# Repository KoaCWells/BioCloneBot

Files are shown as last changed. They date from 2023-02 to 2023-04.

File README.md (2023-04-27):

# BioCloneBot
The BioCloneBot is an open-source automated liquid handler developed to satisfy the requirements of my Master's thesis at Concordia University. Every aspect of the project including the parts, software, and 3D models have been made freely available GPL v3.0 license.

Visual Studio 2022 is required to make modifications to the front-end and the Arduino IDE or VS Code is required to modify the device firmware. Solidworks 2022 is required to open the original 3D model files. STLs have also been provided for printing.

#### Available Under GPL v3.0 License
 Copyright (C) 2023 Ke'Koa Wells

 BioCloneBot is free software: you can redistribute it and/or modify
 it under the terms of the GNU General Public License as published by
 the Free Software Foundation, either version 3 of the License, or
 (at your option) any later version.

 This program is distributed in the hope that it will be useful,
 but WITHOUT ANY WARRANTY; without even the implied warranty of
 MERCHANTABILITY or FITNESS FOR A PARTICULAR PURPOSE.  See the
 GNU General Public License for more details.

 You should have received a copy of the GNU General Public License
 along with this program.  If not, see <http://www.gnu.org/licenses/>.

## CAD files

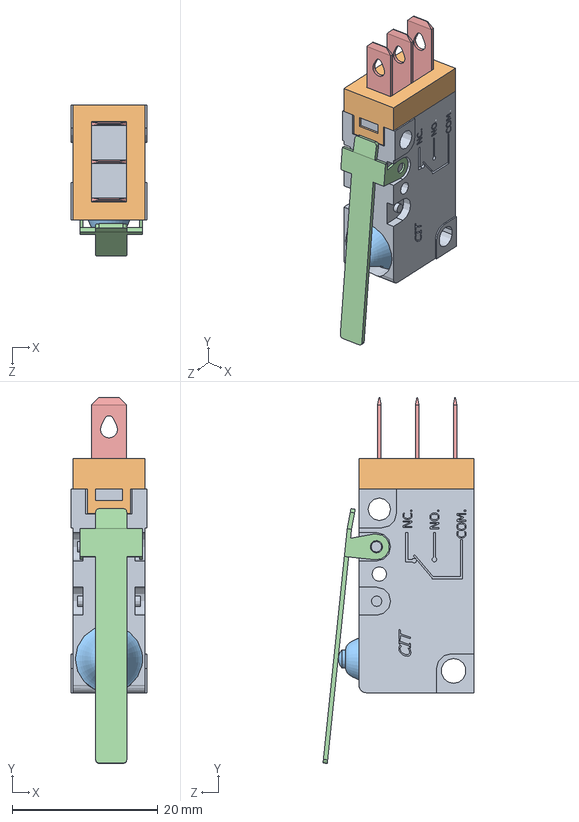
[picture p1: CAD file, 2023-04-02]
CADs/Syringe Pump/[CIT Relay & Switch]LimitSwitch.SLDASM
10.4 x 50.3 x 20.7 mm
VM3_Solid Body.stp
VM3_End Cap2.stp
Rubber Boot Push Button.stp
L88.stp
VM3S_TERMINAL_TEARDROP.stp x 3

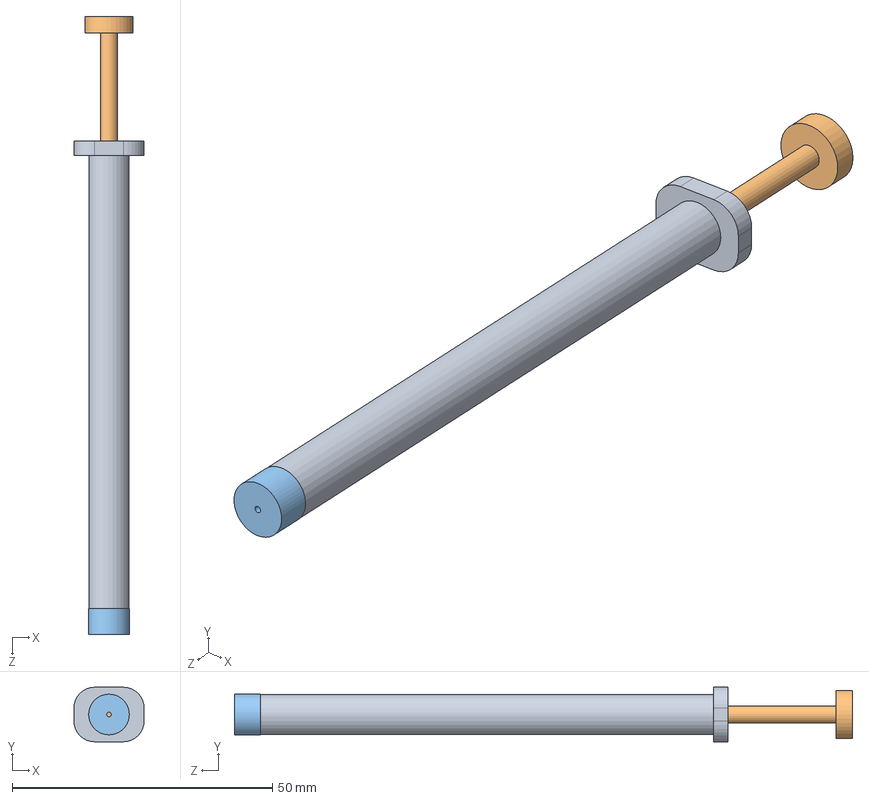
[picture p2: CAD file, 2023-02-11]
CADs/Syringe Pump/Syringe/Syringe.SLDASM
13.5 x 10.5 x 118.7 mm
SyringeBase
Plunger
RNNut

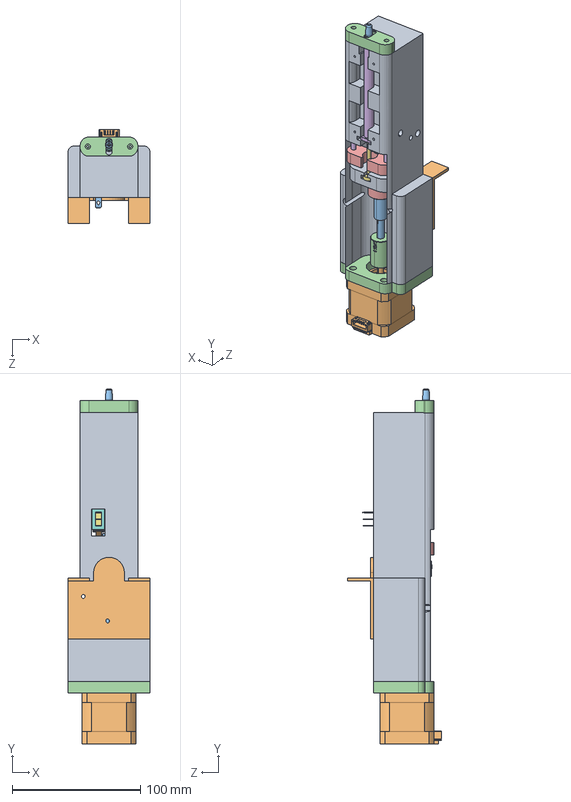
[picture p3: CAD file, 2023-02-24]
CADs/Syringe Pump/SyringePumpAssembly.SLDASM
64.0 x 276.3 x 73.5 mm
SyringePumpBaseV3
[MoonsSteppers] Stepper Motor.step
[Misumi]MTSRA10_100_S30_Q6
[Misumi]MRGS_16_5_6
[Misumi]MTSNR10
SyringeBase
Plunger
RNNut
PlungerHolder
200uLTipAdapter
TipEjectorBottomEnd
TipEjectorTopEnd
TipEjectorShaft x 2
VM3_Solid Body.stp
VM3_End Cap2.stp
Rubber Boot Push Button.stp
L88.stp
VM3S_TERMINAL_TEARDROP.stp x 3
MotorHolder

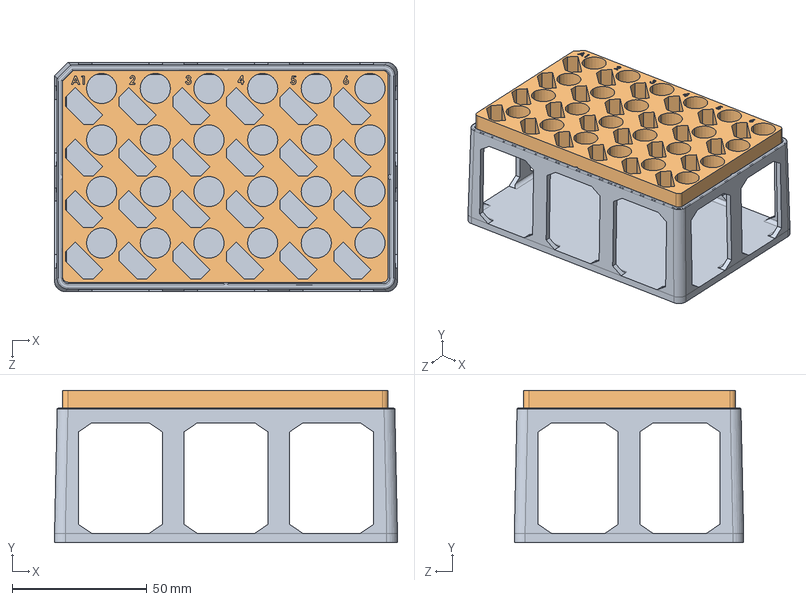
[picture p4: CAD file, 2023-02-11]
CADs/Labware/Tubestand.SLDASM
127.5 x 56.6 x 85.2 mm
OpenTrons_Base_Stand_50mm.step
OpenTrons_1.5mL_rack.step

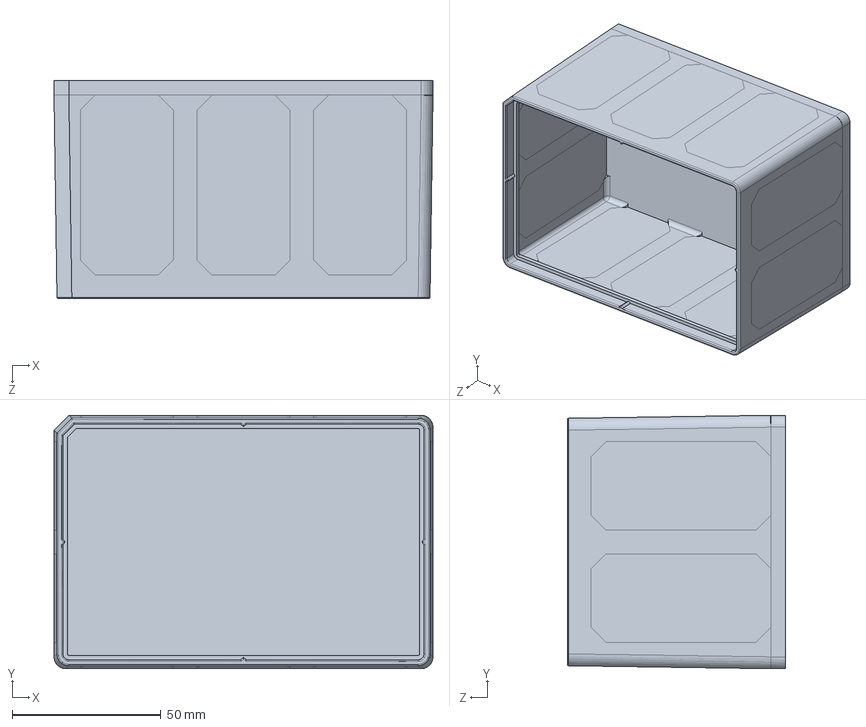
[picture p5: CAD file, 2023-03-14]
CADs/Labware/SolidTubeStand.SLDPRT
127.5 x 85.2 x 73.5 mm

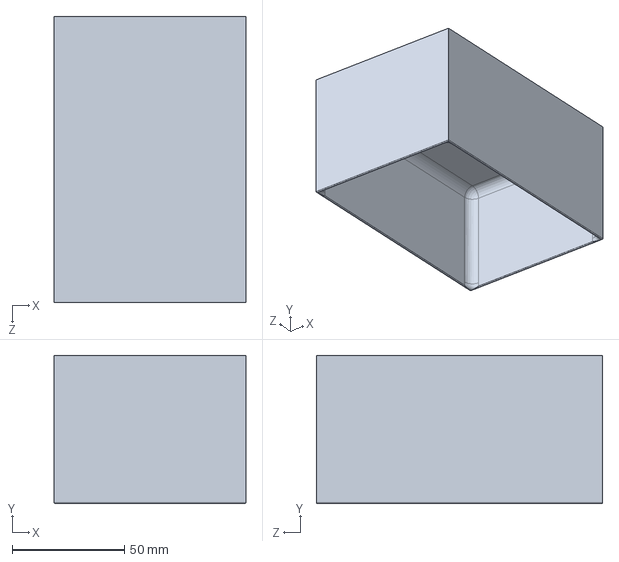
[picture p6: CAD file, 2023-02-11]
CADs/Labware/TrashBin.SLDPRT
85.5 x 66.0 x 127.5 mm

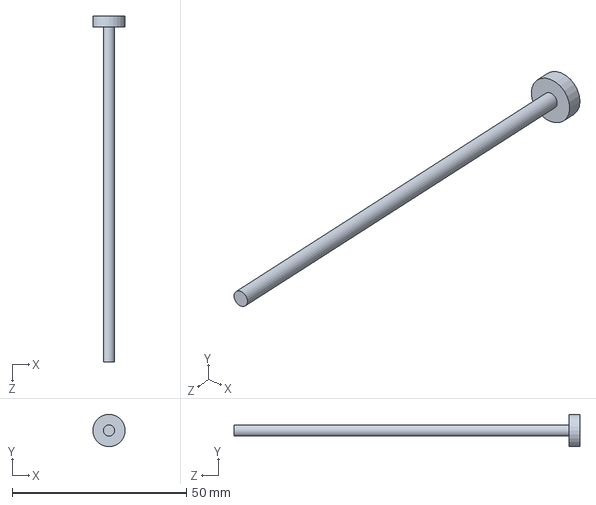
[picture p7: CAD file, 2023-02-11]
CADs/Syringe Pump/Syringe/Plunger.SLDPRT
9.30 x 9.30 x 99.2 mm

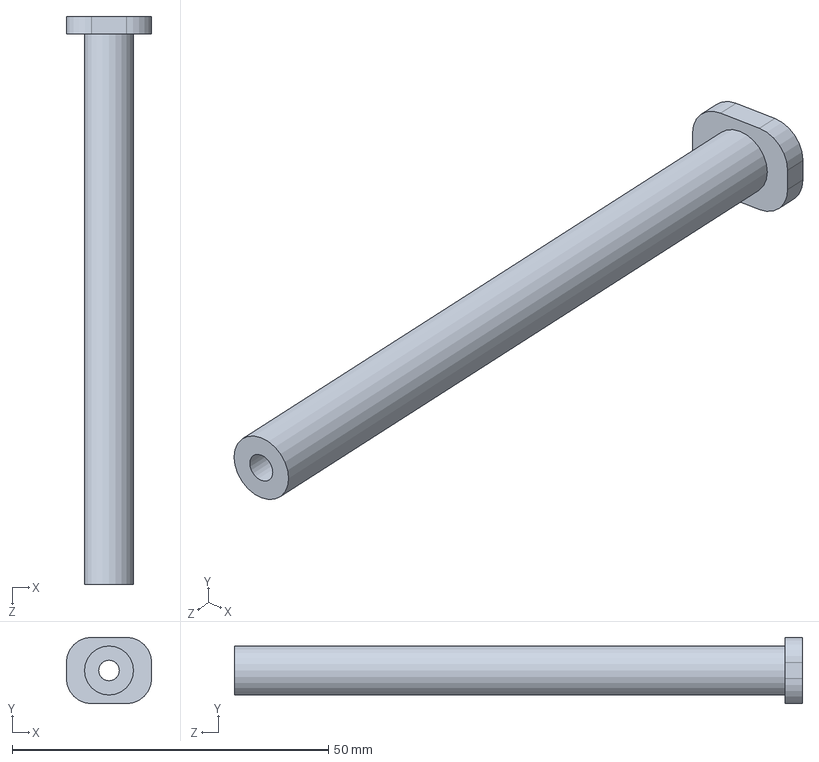
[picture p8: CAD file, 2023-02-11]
CADs/Syringe Pump/Syringe/SyringeBase.SLDPRT
13.5 x 10.5 x 89.8 mm

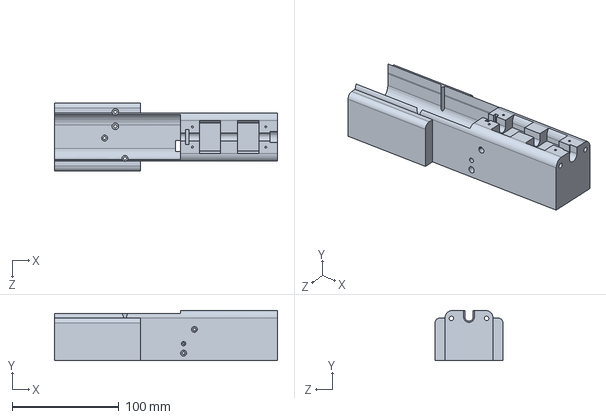
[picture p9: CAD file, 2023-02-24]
CADs/Syringe Pump/SyringePumpBaseV3.SLDPRT
209.0 x 47.0 x 64.0 mm

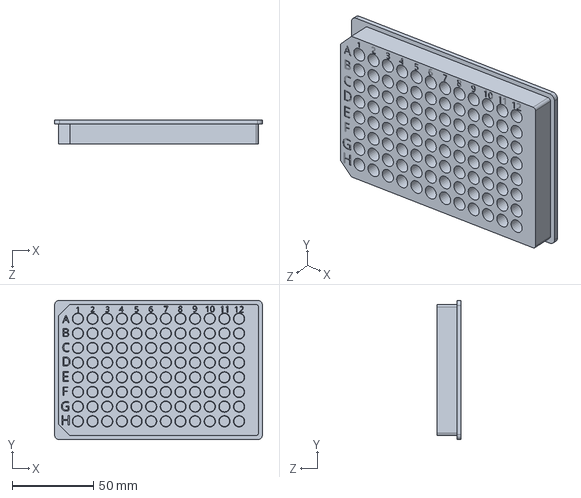
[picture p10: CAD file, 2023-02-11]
CADs/Labware/96 Well Plate, F-bottom, Standard.SLDPRT
127.8 x 85.5 x 14.6 mm

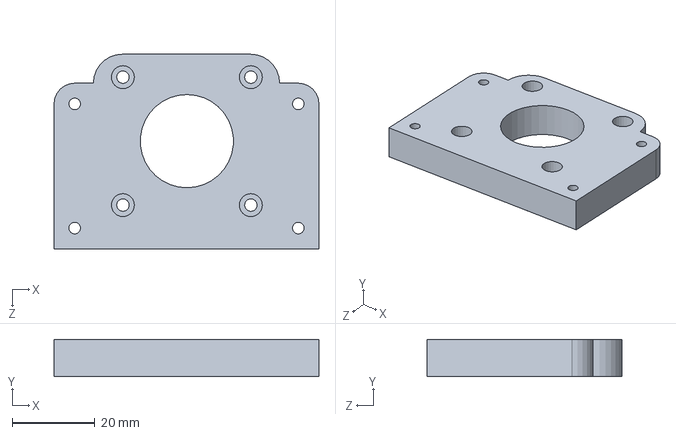
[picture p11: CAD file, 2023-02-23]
CADs/Syringe Pump/MotorHolder.SLDPRT
64.0 x 9.00 x 47.0 mm

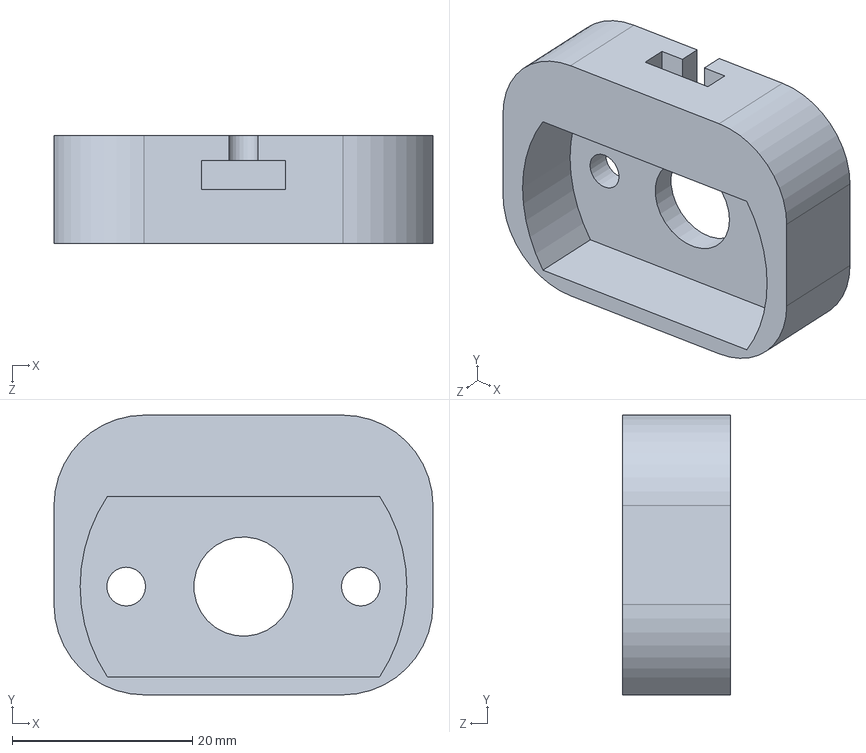
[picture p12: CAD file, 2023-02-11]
CADs/Syringe Pump/Syringe/PlungerHolder.SLDPRT
42.0 x 31.0 x 12.0 mm

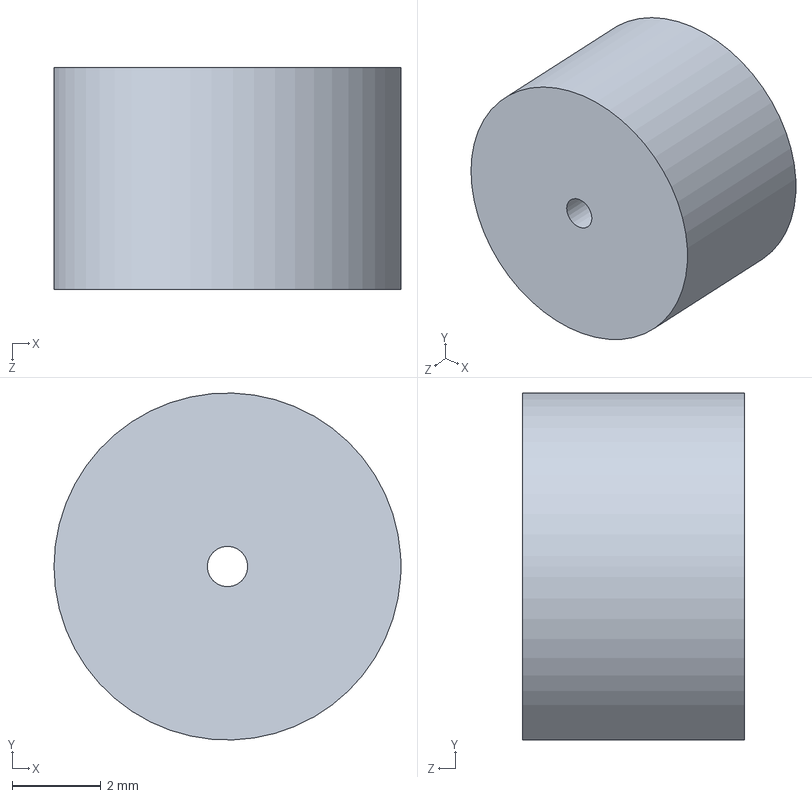
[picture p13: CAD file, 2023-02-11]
CADs/Syringe Pump/Syringe/RNNut.SLDPRT
7.80 x 7.80 x 5.00 mm

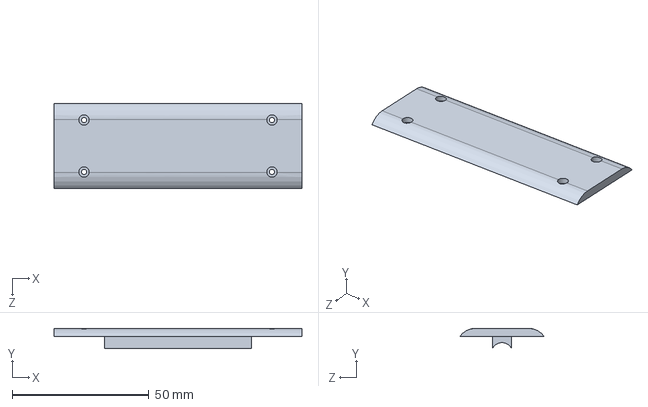
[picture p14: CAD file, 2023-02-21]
CADs/Syringe Pump/SyringeCover.SLDPRT
90.8 x 7.41 x 31.0 mm

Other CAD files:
CADs/Syringe Pump/TipEjectorBottomEnd.SLDPRT
CADs/Syringe Pump/TipEjectorTopEnd.SLDPRT
CADs/Syringe Pump/[MoonsSteppers]StepperMotor.step
CADs/Syringe Pump/SyringeHolder.SLDPRT
CADs/Syringe Pump/10uLTipAdapter.SLDPRT
CADs/Syringe Pump/200uLTipAdapter.SLDPRT
CADs/Syringe Pump/SyringePumpHolder.SLDPRT
CADs/Syringe Pump/TipEjectorShaft.SLDPRT
CADs/Syringe Pump/[Misumi]LeadScrew.sldprt
CADs/Syringe Pump/[Misumi]LeadScrewNut.sldprt
CADs/Syringe Pump/[Misumi]ShaftCoupler.sldprt

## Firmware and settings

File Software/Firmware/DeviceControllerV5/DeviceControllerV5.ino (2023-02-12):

/*****************************************************************************
* __________.__       _________ .__                      __________        __   
* \______   \__| ____ \_   ___ \|  |   ____   ____   ____\______   \ _____/  |_ 
*  |    |  _/  |/  _ \/    \  \/|  |  /  _ \ /    \_/ __ \|    |  _//  _ \   __\
*  |    |   \  (  <_> )     \___|  |_(  <_> )   |  \  ___/|    |   (  <_> )  |  
*  |______  /__|\____/ \______  /____/\____/|___|  /\___  >______  /\____/|__|  
*         \/                  \/                 \/     \/       \/             
* ASCII art source: https://patorjk.com/software/taag/#p=display&f=Graffiti&t=BioCloneBot
* 
* -Author: Koa Wells
* -Github: TBD
* -Contact: koa.wells@gmail.com
* 
* This code was designed to be easily modified by those who want to expand upon 
* the BioCloneBot device.
******************************************************************************/
#include <math.h>

//Refer to Pololu website for documentation on DRV8825 stepper motor https://www.pololu.com/product/2133
#define AXIS_STEPS 200 //Ender 3 Pro step angle 1.8 degrees/200 steps
#define PUMP_STEPS 400//Pump stepper motor angle 0.9 degrees/400 steps
/**************************************************************
* Arduino pins for controlling each stepper motor
* -MS0, MS1, and MS2 are for setting microstep resolution of the driver
* -SLEEP is for enabling/disabling the steeper motor - LOW for sleep/HIGH for enable
* -STEP is the pin for the PWM signal for making the motor move
* -DIR for controlling direction of the stepper motor
* 
* 3-bits for changing microstep resolution (MS2, MS1, MS0 pins)
* -000 - full step
* -001 - half step
* -010 - 1/4 step
* -011 - 1/8 step
* -100 - 1/16 step
* -101/110/111 - 1/32 step
***************************************************************/
//X motor driver pins
#define X_STEP 54
#define X_DIR 55
#define X_ENABLE 38

//Y motor driver pins
#define Y_STEP 60
#define Y_DIR 61
#define Y_ENABLE 56

//Z motor driver pins
#define Z_STEP 46
#define Z_DIR 48
#define Z_ENABLE 62

//PUMP motor driver pins
#define P_STEP 26
#define P_DIR 28
#define P_ENABLE 24

//stepper motor limit switch detection for hardware interrupt/homing
#define X_LIMIT 3
#define Y_LIMIT 14
#define Z_LIMIT 18
#define P_LIMIT 2 //uses X_MAX_PIN from Marlin firmware

/* Global variables for device control
 * axis_step_delay - time in microseconds in between HIGH/LOW pulses for the X,Y,Z motors
 * pump_step_delay - time in microseconds in between HIGH/LOW pulses for the P motors
 * axis_rev_steps - steps per revolution of 3-axis motors
 * pump_rev_steps - steps per revolution of pump motor
 * homing - 0 if device is not in homing mode; limit switches are for emergency stops/1 if device is in homing mode
 * tip_attached - 0 if the pump does not have a tip/1 if the pump does have a tip
 * x_step_dist - distance traveled per step in the X-axis
 * y_step_dist - distance traveled per step in the Y-axis
 * z_step_dist - distance traveled per step in the Z-axis
 * p_step_dist - distance traveled per step in the P-axis
 * aspiriate_vol - volume to be aspirated by pump
 * dispense_vol - volume to be dispensed by pump + 50 ul of leading air gap
 * x_dist - pump travel destination on x-axis
 * y_dist - pump travel destination on y-axis
 * z_dist - pump travel destination on z-axis
 * host_message - raw message from the host including 4-bit command and command parameters
 * curr_command - first 4 bits of host_message for determining what function the device should perform
 * prev_command - previous command that was run
 */
int axis_step_delay;
int pump_step_delay;
int axis_rev_steps;
int pump_rev_steps;
int homing;
int message_character;

double x_step_dist;
double y_step_dist;
double z_step_dist;
double p_step_dist;
double aspirate_vol;
double dispense_vol;
double mix_vol;
double mix_count;
double x_dist;
double y_dist;
double z_dist;
double vol_per_step;
char x_dir;
char y_dir;
char z_dir;
char distance[6];
char volume[6];
char mix_qty[3];
char *ptr_end;
char *ptr_end2;
String host_message;
String confirmation_message;
String curr_command;
String prev_command;
bool message_complete;

void setup() {
  Serial.begin(9600);

  pump_step_delay = 500; //time delay between HIGH/LOW digital control signal in microseconds
  pump_rev_steps = 400; //steps per revolution
  p_step_dist = 157E-6; //mm per step
  //0.041667 for 500 uL syringe
  //0.020774 for 250 uL syringe
  //0.004166 for 50 uL gastight syringe
  vol_per_step = 0.020774;

  //sets all stepper motor control pins to output
  pinMode(X_STEP, OUTPUT);
  pinMode(X_DIR, OUTPUT);
  pinMode(X_ENABLE, OUTPUT);
  pinMode(Y_STEP, OUTPUT);
  pinMode(Y_DIR, OUTPUT);
  pinMode(Y_ENABLE, OUTPUT);
  pinMode(Z_STEP, OUTPUT);
  pinMode(Z_DIR, OUTPUT);
  pinMode(Z_ENABLE, OUTPUT);
  pinMode(P_STEP, OUTPUT);
  pinMode(P_DIR, OUTPUT);
  pinMode(P_ENABLE, OUTPUT);

  //define limit switch pins and pullup to high voltage
  pinMode(X_LIMIT, INPUT_PULLUP);
  pinMode(Y_LIMIT, INPUT_PULLUP);
  pinMode(Z_LIMIT, INPUT_PULLUP);
  pinMode(P_LIMIT, INPUT_PULLUP);

  //sets default direction of stepper motors to point towards the limit switches
  digitalWrite(X_DIR, LOW);
  digitalWrite(Y_DIR, LOW);
  digitalWrite(Z_DIR, LOW);
  digitalWrite(P_DIR, LOW);

  //attach interupts for the limit switches
  attachInterrupt(digitalPinToInterrupt(X_LIMIT), xLimitPressed, FALLING);
  attachInterrupt(digitalPinToInterrupt(Y_LIMIT), yLimitPressed, FALLING);
  attachInterrupt(digitalPinToInterrupt(Z_LIMIT), zLimitPressed, FALLING);
  attachInterrupt(digitalPinToInterrupt(P_LIMIT), pLimitPressed, FALLING);

  setMicrostepping(32); //sets microstepping of all 3-axis drivers to 1/32
  homing = 0;
}

void loop() {
  /*
 * List of possible device commands
 * -0000 home device: homes x, y, z, and p stepper motors
 * -0001 move pump: move carriage to x, y, z location (XXX.XX location in mm)
 * -0010 remove tip: remove tip and leave room for trailing air gap (25.0uL)
 * -0011 aspirate volume: aspirate volume in ul (XXX.XX ul)
 * -0100 dispense volume: dispense volume in ul + 25 ul (XXX.XX ul)
 * -0101 mix: mix volume XXX number of times
 * -1110 enable stepper motors: sets sleep pin of all motor drivers to HIGH
 * -1111 disable stepper motors: sets sleep pin of all motor drivers to LOW
 */
  while(Serial.available() > 0){
    Serial.flush();
    curr_command = "";
    x_dist = 0.0;
    y_dist = 0.0;
    z_dist = 0.0;
    aspirate_vol = 0.0;
    dispense_vol = 0.0;
    mix_vol = 0.0;
    mix_count = 0.0;
    
    host_message = receiveHostMessage();

    if(host_message == "ping"){
      confirmation_message = "#pong%";
      for(int i = 0; i < confirmation_message.length(); i++){
        Serial.write(confirmation_message[i]);
      }
    }

    //decodes first 4 characters of host_message to determine command
    for(int i = 0; i < 4; i++){
      curr_command += host_message[i];
    }
    
    if(curr_command == "0000"){ //home motors
      homeCarriage();
      sendCompletionMessage();
    }
    else if(curr_command == "0001"){ //move pump to x, y, z location
      x_dir = host_message.charAt(4);
      y_dir = host_message.charAt(5);
      z_dir = host_message.charAt(6);
      
      for(int i = 7; i < 13; i++){
        distance[i-7] = host_message[i];
      }
      x_dist = strtod(distance, &ptr_end);

      for(int i = 13; i < 19; i++){
        distance[i-13]= host_message[i];
      }
      y_dist = strtod(distance, &ptr_end);

      for(int i = 19; i < 25; i++){
        distance[i-19]= host_message[i];
      }
      z_dist = strtod(distance, &ptr_end);

      movePump(x_dir,y_dir,z_dir,x_dist,y_dist,z_dist);
      sendCompletionMessage();
    }
    else if(curr_command == "0010"){ //remove tip
      removeTip();
      sendCompletionMessage();
    }
    else if(curr_command == "0011"){ //aspirate volume
      for(int i = 4; i < 10; i++){
        volume[i-4] = host_message[i];
      }
      aspirate_vol = strtod(volume, &ptr_end);
      aspirate(aspirate_vol);
      sendCompletionMessage();
    }
    else if(curr_command == "0100"){  //dispense volume
      for(int i = 4; i < 10; i++){
        volume[i-4] = host_message[i];
      }
      dispense_vol = strtod(volume, &ptr_end);
      dispense(dispense_vol);
      sendCompletionMessage();
    }
    else if(curr_command == "0101"){  //mix volume
      for(int i = 4; i < 7; i++){
        if(i-4 == 0){
          mix_count += 100*(host_message[i] - '0');
        }
        else if(i-4 == 1){
          mix_count += 10*(host_message[i] - '0');
        }
        else if(i-4 == 2){
          mix_count += 1*(host_message[i] - '0');
        }
      }

      for(int i = 7; i < 12; i++){
        volume[i-7] = host_message[i];
      }
      mix_vol = strtod(volume, &ptr_end2);
      mix(mix_count, mix_vol);
      sendCompletionMessage();
    }
    else if(curr_command == "1111"){ //disable stepper motors
      disableMotors();
      sendCompletionMessage();
    }
  }
  prev_command = curr_command;
}

 /*homeCarriage
  * homeCarriage resets all stepper motors to their homed position.
  * Works by enabling each motor driver by setting each corresponding
  * SLEEP pin to HIGH, then setting the DIR pin to match the direction
  * of the limit switch. Each motor then moves until the limit switch
  * is pressed and backs off until the switch is no longer pressed.
  * This is the homed position.
  */
void homeCarriage(){
  enableMotors(); //enables all stepper motor drivers

  homing = 1; //disables limit switch overrupts for the purpose of homing
  int count = 0;
  //sets initial direction of all motors towards their limit switches
  digitalWrite(X_DIR, LOW);
  digitalWrite(Y_DIR, LOW);
  digitalWrite(Z_DIR, LOW);
  digitalWrite(P_DIR, HIGH);

  //home x-axis
  //move towards limit switch until it is pressed
  while(digitalRead(X_LIMIT)){
    digitalWrite(X_STEP, HIGH);
    delayMicroseconds(axis_step_delay);
    digitalWrite(X_STEP,LOW);
    delayMicroseconds(axis_step_delay);
  }
  delay(100);
  //move away from limit switch until it isn't pressed
  digitalWrite(X_DIR, HIGH);
  while(!digitalRead(X_LIMIT)){
    digitalWrite(X_STEP, HIGH);
    delayMicroseconds(axis_step_delay);
    digitalWrite(X_STEP, LOW);
    delayMicroseconds(axis_step_delay);
  }
  //move away from limit switch just a bit more
  for(int i = 0; i < 20; i++){
    digitalWrite(X_STEP, HIGH);
    delayMicroseconds(axis_step_delay);
    digitalWrite(X_STEP, LOW);
    delayMicroseconds(axis_step_delay);
  }
  digitalWrite(X_DIR, LOW);

  //home y-axis
  //move towards limit switch until it is pressed
  while(digitalRead(Y_LIMIT)){
    digitalWrite(Y_STEP, HIGH);
    delayMicroseconds(axis_step_delay);
    digitalWrite(Y_STEP,LOW);
    delayMicroseconds(axis_step_delay);
  }
  delay(100);
  //move away from limit switch until it isn't pressed
  digitalWrite(Y_DIR, HIGH);
  while(!digitalRead(Y_LIMIT)){
    digitalWrite(Y_STEP, HIGH);
    delayMicroseconds(axis_step_delay);
    digitalWrite(Y_STEP, LOW);
    delayMicroseconds(axis_step_delay);
  }
  //move away from limit switch a little bit more
  for(int i = 0; i < 20; i++){
    digitalWrite(Y_STEP, HIGH);
    delayMicroseconds(axis_step_delay);
    digitalWrite(Y_STEP, LOW);
    delayMicroseconds(axis_step_delay);
  }
  digitalWrite(Y_DIR, LOW);

  //home z-axis
  //move towards limit switch until it is pressed
  while(digitalRead(Z_LIMIT)){
    digitalWrite(Z_STEP, HIGH);
    delayMicroseconds(axis_step_delay);
    digitalWrite(Z_STEP,LOW);
    delayMicroseconds(axis_step_delay);
  }
  delay(100);
  //move away from limit switch until it isn't pressed
  digitalWrite(Z_DIR, HIGH);
  while(!digitalRead(Z_LIMIT)){
    digitalWrite(Z_STEP, HIGH);
    delayMicroseconds(axis_step_delay);
    digitalWrite(Z_STEP, LOW);
    delayMicroseconds(axis_step_delay);
  }
  //move away from limit switch a little bit more
  for(int i = 0; i < 10; i++){
    digitalWrite(Z_STEP, HIGH);
    delayMicroseconds(axis_step_delay);
    digitalWrite(Z_STEP, LOW);
    delayMicroseconds(axis_step_delay);
  }
  digitalWrite(Z_DIR, LOW);

  //home p-axis
  while(digitalRead(P_LIMIT)){
    digitalWrite(P_STEP, HIGH);
    delayMicroseconds(pump_step_delay);
    digitalWrite(P_STEP,LOW);
    delayMicroseconds(pump_step_delay);
  }
  delay(50);
  digitalWrite(P_DIR, LOW);
  while(!digitalRead(P_LIMIT)){
    digitalWrite(P_STEP, HIGH);
    delayMicroseconds(pump_step_delay);
    digitalWrite(P_STEP, LOW);
    delayMicroseconds(pump_step_delay);
  }
  //back off until pump ejector is flush with base
  for(int i = 0; i < 800; i++){
    digitalWrite(P_STEP, HIGH);
    delayMicroseconds(pump_step_delay);
    digitalWrite(P_STEP, LOW);
    delayMicroseconds(pump_step_delay);
  }
  //back off pump for 25.0 uL trailing air gap
  //25.0 for 250 uL syringe
  //5.0 for 50 uL syringe
  for(int i = 0; i < 25.0/vol_per_step; i++){
    digitalWrite(P_STEP, HIGH);
    delayMicroseconds(pump_step_delay);
    digitalWrite(P_STEP, LOW);
    delayMicroseconds(pump_step_delay);
  }

  digitalWrite(P_DIR, LOW);
  movePump('1', '1', '0', 012.00, 033.00, 0.0);
  //sets homing to 0 re-enabling the normal functionality of the limit switches as emergency stops
  //and sets carriage location to (0.0, 0.0, 0.0) and syringe volume to 0
  homing = 0;
}

void movePump(char x_direction, char y_direction, char z_direction, double x_dist, double y_dist, double z_dist){
  if(x_direction == '0'){
      digitalWrite(X_DIR, LOW);
  }
  else if(x_direction == '1'){
    digitalWrite(X_DIR, HIGH);
  }

  for(double i = 0; i < (x_dist/.00625); i++){
    digitalWrite(X_STEP, HIGH);
    delayMicroseconds(axis_step_delay);
    digitalWrite(X_STEP, LOW);
    delayMicroseconds(axis_step_delay);
  }

  if(y_direction == '0'){
      digitalWrite(Y_DIR, LOW);
  }
  else if(y_direction == '1'){
    digitalWrite(Y_DIR, HIGH);
  }

  for(double i = 0; i < (y_dist/.00625); i++){
    digitalWrite(Y_STEP, HIGH);
    delayMicroseconds(axis_step_delay);
    digitalWrite(Y_STEP, LOW);
    delayMicroseconds(axis_step_delay);
  }

  if(z_direction == '0'){
      digitalWrite(Z_DIR, LOW);
  }
  else if(z_direction == '1'){
    digitalWrite(Z_DIR, HIGH);
  }
  
  digitalWrite(Z_DIR, z_direction - '0');

  for(double i = 0; i < (z_dist/.00125); i++){
    digitalWrite(Z_STEP, HIGH);
    delayMicroseconds(axis_step_delay);
    digitalWrite(Z_STEP, LOW);
    delayMicroseconds(axis_step_delay);
  }
}

void removeTip(){
  //move to max Z
  //move to center of tip dispenser
  //move
  homing = 1;
  digitalWrite(P_DIR, HIGH);
  while(digitalRead(P_LIMIT)){
    digitalWrite(P_STEP, HIGH);
    delayMicroseconds(pump_step_delay);
    digitalWrite(P_STEP,LOW);
    delayMicroseconds(pump_step_delay);
  }
  delay(50);
  digitalWrite(P_DIR, LOW);
  while(!digitalRead(P_LIMIT)){
    digitalWrite(P_STEP, HIGH);
    delayMicroseconds(pump_step_delay);
    digitalWrite(P_STEP, LOW);
    delayMicroseconds(pump_step_delay);
  }
  //back off until pump ejector is flush with base
  for(int i = 0; i < 800; i++){
    digitalWrite(P_STEP, HIGH);
    delayMicroseconds(pump_step_delay);
    digitalWrite(P_STEP, LOW);
    delayMicroseconds(pump_step_delay);
  }

  homing = 0;
}

void aspirate(double volume){
  homing = 1;
  digitalWrite(P_DIR, LOW);
  for(int i = 0; i < volume/vol_per_step; i++){
    digitalWrite(P_STEP, HIGH);
    delayMicroseconds(pump_step_delay);
    digitalWrite(P_STEP, LOW);
    delayMicroseconds(pump_step_delay);
  }
  homing = 0;
}

void dispense(double volume){
  homing = 1;
  digitalWrite(P_DIR, HIGH);
  for(int i = 0; i < volume/vol_per_step; i++){
    digitalWrite(P_STEP, HIGH);
    delayMicroseconds(pump_step_delay);
    digitalWrite(P_STEP, LOW);
    delayMicroseconds(pump_step_delay);
  }
  homing = 0;
}

void mix(double mix_count, double volume)
{
  for(int i = 0; i < mix_count; i++){
    digitalWrite(P_DIR, LOW);
    for(int j = 0; j < volume/vol_per_step; j++){
      digitalWrite(P_STEP, HIGH);
      delayMicroseconds(pump_step_delay);
      digitalWrite(P_STEP, LOW);
      delayMicroseconds(pump_step_delay);
    }
    digitalWrite(P_DIR, HIGH);
    for(int j = 0; j < volume/vol_per_step; j++){
      digitalWrite(P_STEP, HIGH);
      delayMicroseconds(pump_step_delay);
      digitalWrite(P_STEP, LOW);
      delayMicroseconds(pump_step_delay);
    }
  }
}

//adjusts microstepping, timing, and steps/revolution for each motor
void setMicrostepping(int step_size){
  switch(step_size){
    case 1: //000 - full step
      axis_step_delay = 2000;
      axis_rev_steps = 200;
      x_step_dist = 2000E-7;
      y_step_dist = 2000E-7;
      z_step_dist = 4000E-5;
      break;
    case 2: //001 - half step
      axis_step_delay = 1000;
      axis_rev_steps = 400;
      x_step_dist = 1000E-7;
      y_step_dist = 1000E-7;
      z_step_dist = 2000E-5;
      break;
    case 4: //010 - quarter step
      axis_step_delay = 500;
      //pump_step_delay = 250;
      axis_rev_steps = 800;
      //pump_rev_steps = 1600;
      x_step_dist = 500E-7;
      y_step_dist = 500E-7;
      z_step_dist = 1000E-5;
      break;
    case 8: //010 - 1/8 step
      axis_step_delay = 250;
      //pump_step_delay = 125;
      axis_rev_steps = 1600;
      //pump_rev_steps = 3200;
      x_step_dist = 250E-7;
      y_step_dist = 250E-7;
      z_step_dist = 500E-5;
      break;
    case 16: //011 - 1/16 step

      axis_step_delay = 125;
      axis_rev_steps = 3200;
      x_step_dist = 125E-7;
      y_step_dist = 125E-7;
      z_step_dist = 250E-5;
      break;
    case 32: //100 - 1/32nd step
      axis_step_delay = 63;
      //axis_step_delay = 125;
      axis_rev_steps = 6400;
      x_step_dist = 63E-7;
      y_step_dist = 63E-7;
      z_step_dist = 125E-5;
      break;
  }
}

void enableMotors(){
  digitalWrite(X_SLEEP, HIGH);
  digitalWrite(Y_SLEEP, HIGH);
  digitalWrite(Z_SLEEP, HIGH);
  digitalWrite(P_SLEEP, HIGH);
}

void disableMotors(){
  digitalWrite(X_SLEEP, LOW);
  digitalWrite(Y_SLEEP, LOW);
  digitalWrite(Z_SLEEP, LOW);
  digitalWrite(P_SLEEP, LOW);
}

void startSerialConnection(){
  bool message_begin = false;
  bool message_complete = false;
  host_message = "";
  confirmation_message = "#pong%";
  message_character = -1;
  Serial.flush();
  //waits for message from serial to establish connection with host computer
  
  while(message_complete == false){
    message_character = Serial.read();
    if(message_character != -1){
      if((char)message_character == '#'){
        message_begin = true;
      }
      
      if(message_begin == true){
        if((char) message_character != '#' && (char)message_character != '%'){
          host_message += (char)message_character;
        }
        else{
          if(host_message == "ping"){
            digitalWrite(CONN_LED, HIGH);
            message_complete = true;
            for(int i = 0; i < confirmation_message.length(); i++){
              Serial.write(confirmation_message[i]);
            }
          }
        }
      }
    }
  }
}

void sendCompletionMessage(){
  String completion_message = "#complete%";
  for(int i = 0; i < completion_message.length(); i++){
    Serial.write(completion_message[i]);
  }
}

String receiveHostMessage(){
  bool message_begin = false;
  bool message_complete = false;
  host_message = "";
  confirmation_message = "#pong%";
  message_character = -1;
  Serial.flush();
  //waits for message from serial to establish connection with host computer
  
  while(message_complete == false){
    message_character = Serial.read();
    if(message_character != -1){
      if((char)message_character == '#'){
        message_begin = true;
      }
      
      if(message_begin == true){
        if((char) message_character != '#' && (char)message_character != '%'){
          host_message += (char)message_character;
        }
        else if((char)message_character == '%'){
          message_complete = true;
        }
      }
    }
  }
  return host_message;
}
void xLimitPressed(){
  if(homing == 0){
    //digitalWrite(X_SLEEP, LOW);
  }
}

void yLimitPressed(){
  if(homing == 0){
    //digitalWrite(Y_SLEEP, LOW);
  }
}

void zLimitPressed(){
  if(homing == 0){
    //digitalWrite(Z_SLEEP, LOW);
  }
}

void pLimitPressed(){
  if(homing == 0){
    digitalWrite(P_SLEEP, LOW);
  }
}

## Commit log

2022-03-25 Add microstep pin comments and add steps/rev variables
2022-06-08 Fixed serial communication between Arduino and host. Cleaned up a bunch of other bugs that prevented experiments to run.
    [DeviceControllerV4.ino]
2022-09-21 Add reset of volumes and counters at top of loop
    [DeviceControllerV4.ino]
2022-12-11 Modify labware .cs files and device firmware.
2023-02-11 Add CADs, documentation folder, and file restructure
    [10uLTipAdapter.SLDPRT, 10uLTipEjectorBottomEnd.SLDPRT, 200uLTipAdapter.SLDPRT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]
2023-02-11 add 2 SyringePumpBase test based on version 3.
    [SyringePumpBaseV3_test1.SLDPRT, SyringePumpBaseV3_test2.SLDPRT]
2023-02-12 Update firmware for mks board and pump base test2
    [SyringePumpBaseV3_test2.SLDPRT]
2023-02-13 Update tip ejector parts for syringe removal
    [200uLTipEjectorBottomEnd.SLDPRT, TipEjectorBottomEnd.SLDPRT, TipEjectorTopEnd.SLDPRT]
2023-02-14 Update syringe basev3 and syringe cover
    [SyringeCover.SLDPRT, SyringePumpAssembly.SLDASM, SyringePumpBaseV3.SLDPRT]
2023-02-14 Fix sketch errors
    [SyringePumpAssembly.SLDASM, SyringePumpBaseV3.SLDPRT]
2023-02-15 add 3mm more to the extruded base with the half circule that is touching the syringe
    [SyringeCover.SLDPRT]
2023-02-15 Add beautiful filets
    [SyringeCover.SLDPRT]
2023-02-21 Shorten Boss-extrude2 by 1mm
    [SyringeCover.SLDPRT]
2023-02-23 Fix relation bugs and redimension screw holes
    [MotorHolder.SLDPRT, SyringePumpAssembly.SLDASM, SyringePumpBaseV3.SLDPRT]
2023-02-24 Fix issue with cut-extrude100
    [SyringePumpAssembly.SLDASM, SyringePumpBaseV3.SLDPRT]
2023-03-14 Add SolidTubeStand labware
    [SolidTubeStand.SLDPRT]
2023-04-02 Clean up old parts and rename several parts
    [D3V_013_1C23.step, LimitSwitch.SLDPRT, SyringePumpBaseV1.SLDPRT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]
2023-04-02 Fix issue with limit switch assembly
    [[CIT Relay & Switch]LimitSwitch.SLDASM]
